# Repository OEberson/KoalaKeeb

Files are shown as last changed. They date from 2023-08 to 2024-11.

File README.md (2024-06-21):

# KoalaKeeb

In this repo, I am sharing with you my ideal split keyboard, The KoalaKeeb. It is heavily inspired by the [Ferris Sweep](https://github.com/davidphilipbarr/Sweep) and borrows its physical layout. What it adds is ten SK6812 MINI-E LEDs next to the MCU that will be used to display the current battery status or bluetooth profile and a cute koala logo. I will implement the LED functionality in [my ZMK fork](https://github.com/OEberson/zmkoala) soon.

Note that the current PCB version has some imperfections that I will improve on in a second revision.

[Link to my layout](https://github.com/OEberson/zmk-config)

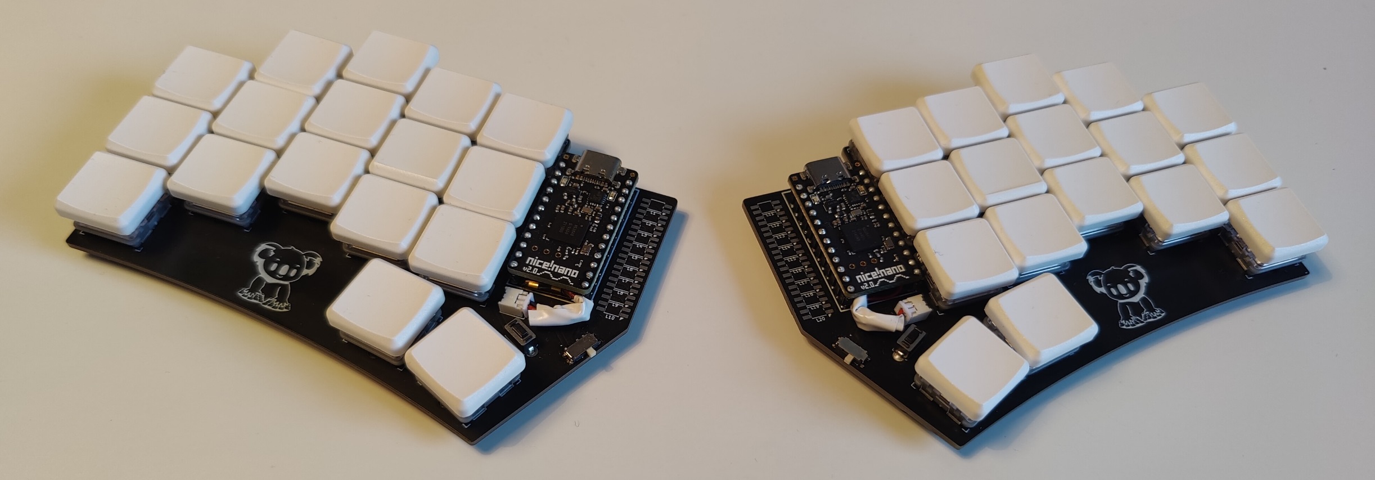
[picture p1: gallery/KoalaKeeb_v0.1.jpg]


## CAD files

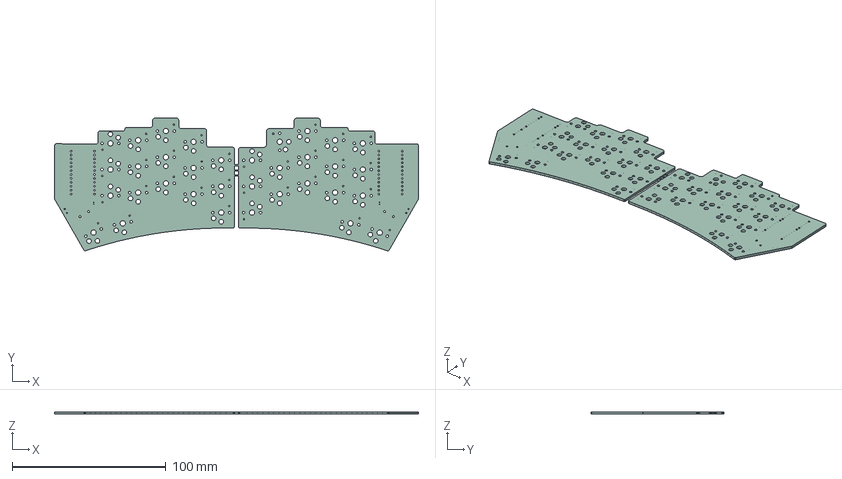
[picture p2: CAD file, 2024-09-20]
KiCad/KoalaKeeb/KoalaKeeb/KoalaKeeb.step
236.6 x 86.3 x 1.60 mm

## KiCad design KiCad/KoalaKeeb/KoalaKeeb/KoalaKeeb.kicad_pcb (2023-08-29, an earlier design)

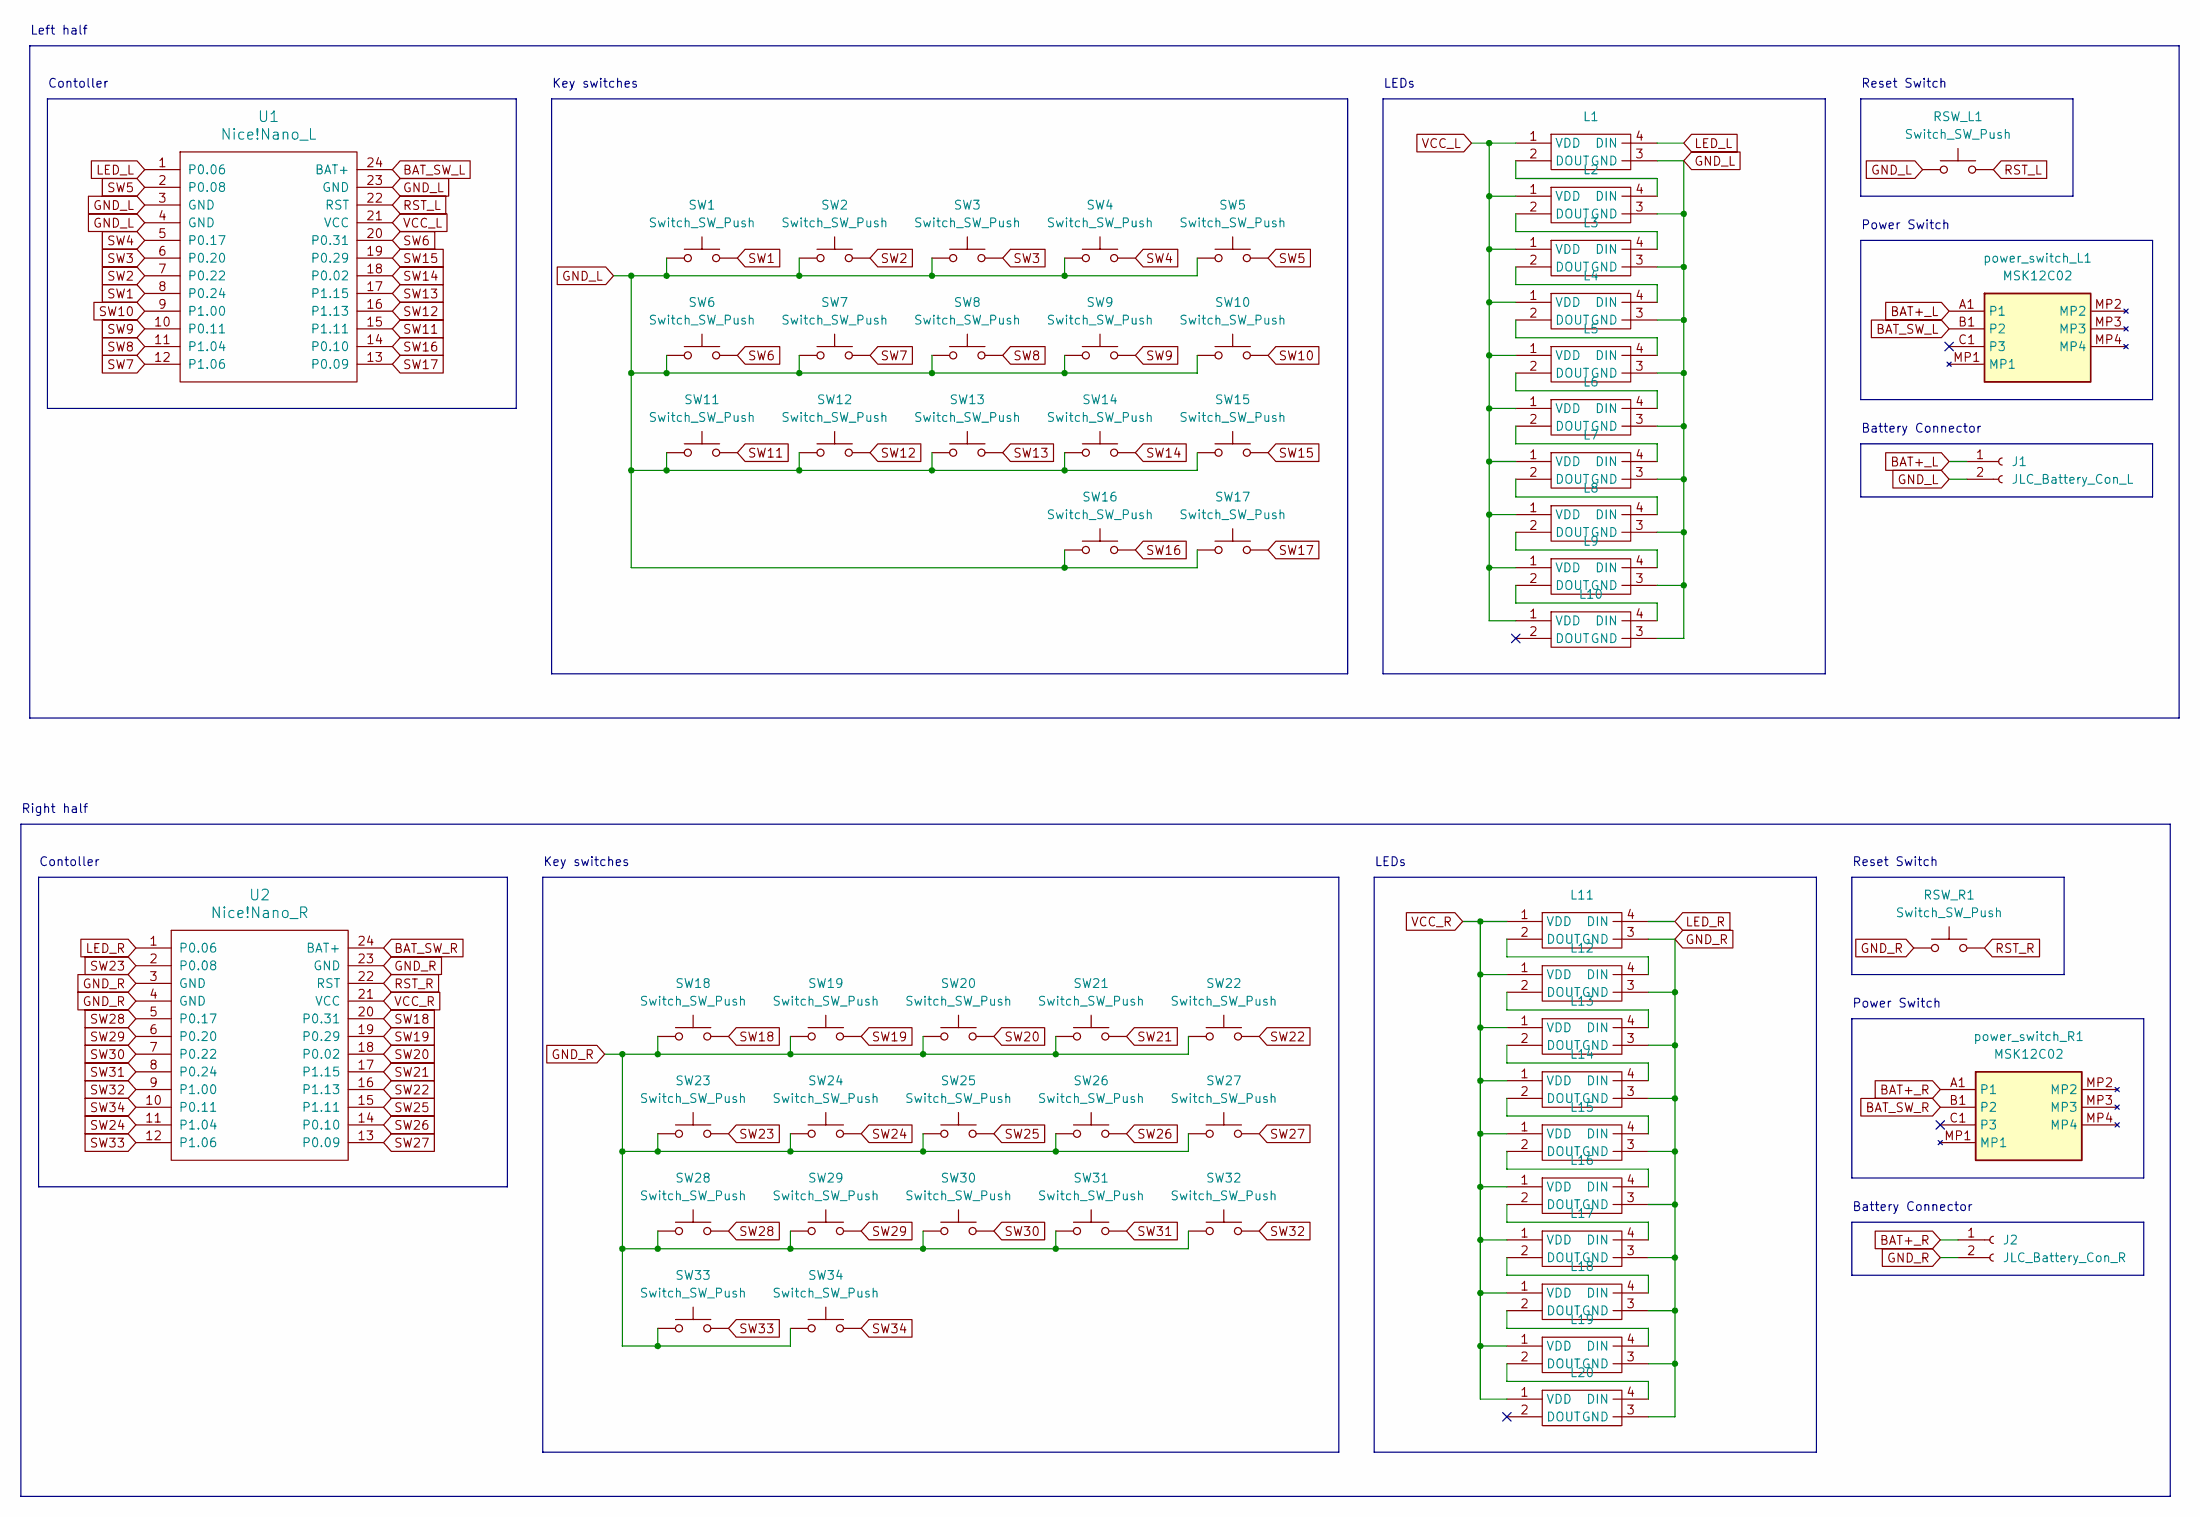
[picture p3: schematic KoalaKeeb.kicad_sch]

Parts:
J1: JLC_Battery_Con_L; JLC 2Pin
J2: JLC_Battery_Con_R; JLC 2Pin
L1, L2, L3, L4, L5, L6, L7, L8, L9, L10, L11, L12, L13, L14, L15, L16, L17, L18, L19, L20: SK6812-MINI-E
RSW_L1: Switch_SW_Push; TS-1136-4.3
RSW_R1: Switch_SW_Push; TS-1136-4.3
SW1, SW2, SW3, SW4, SW5, SW6, SW7, SW8, SW9, SW10, SW11, SW12, SW13, SW14, SW15, SW16, SW17, SW18, SW19, SW20, SW21, SW22, SW23, SW24, SW25, SW26, SW27, SW28, SW29, SW30, SW31, SW32, SW33, SW34: Switch_SW_Push; Kailh_socket_PG1350
U1: Nice!Nano_L; nice!nano
U2: Nice!Nano_R; nice!nano
power_switch_L1: MSK12C02; Manufacturer_Part_Number MSK12C02
power_switch_R1: MSK12C02; Manufacturer_Part_Number MSK12C02

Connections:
BAT+_L: J1.1, power_switch_L1.A1 (P1)
BAT+_R: J2.1, power_switch_R1.A1 (P1)
BAT_SW_L: U1.24 (BAT+), power_switch_L1.B1 (P2)
BAT_SW_R: U2.24 (BAT+), power_switch_R1.B1 (P2)
GND_L: J1.2, L1.3 (GND), L2.3 (GND), L3.3 (GND), L4.3 (GND), L5.3 (GND), L6.3 (GND), L7.3 (GND), L8.3 (GND), L9.3 (GND), L10.3 (GND), RSW_L1.1, SW1.1, SW2.1, SW3.1, SW4.1, SW5.1, SW6.1, SW7.1, SW8.1, SW9.1, SW10.1, SW11.1, SW12.1, SW13.1, SW14.1, SW15.1, SW16.1, SW17.1, U1.3 (GND), U1.4 (GND), U1.23 (GND)
GND_R: J2.2, L11.3 (GND), L12.3 (GND), L13.3 (GND), L14.3 (GND), L15.3 (GND), L16.3 (GND), L17.3 (GND), L18.3 (GND), L19.3 (GND), L20.3 (GND), RSW_R1.1, SW18.1, SW19.1, SW20.1, SW21.1, SW22.1, SW23.1, SW24.1, SW25.1, SW26.1, SW27.1, SW28.1, SW29.1, SW30.1, SW31.1, SW32.1, SW33.1, SW34.1, U2.3 (GND), U2.4 (GND), U2.23 (GND)
LED_L: L1.4 (DIN), U1.1 (P0.06)
LED_R: L11.4 (DIN), U2.1 (P0.06)
unnamed: L1.2 (DOUT), L2.4 (DIN)
unnamed: L2.2 (DOUT), L3.4 (DIN)
unnamed: L3.2 (DOUT), L4.4 (DIN)
unnamed: L4.2 (DOUT), L5.4 (DIN)
unnamed: L5.2 (DOUT), L6.4 (DIN)
unnamed: L6.2 (DOUT), L7.4 (DIN)
unnamed: L7.2 (DOUT), L8.4 (DIN)
unnamed: L8.2 (DOUT), L9.4 (DIN)
unnamed: L9.2 (DOUT), L10.4 (DIN)
unnamed: L11.2 (DOUT), L12.4 (DIN)
unnamed: L12.2 (DOUT), L13.4 (DIN)
unnamed: L13.2 (DOUT), L14.4 (DIN)
unnamed: L14.2 (DOUT), L15.4 (DIN)
unnamed: L15.2 (DOUT), L16.4 (DIN)
unnamed: L16.2 (DOUT), L17.4 (DIN)
unnamed: L17.2 (DOUT), L18.4 (DIN)
unnamed: L18.2 (DOUT), L19.4 (DIN)
unnamed: L19.2 (DOUT), L20.4 (DIN)
RST_L: RSW_L1.2, U1.22 (RST)
RST_R: RSW_R1.2, U2.22 (RST)
SW1: SW1.2, U1.8 (P0.24)
SW2: SW2.2, U1.7 (P0.22)
SW3: SW3.2, U1.6 (P0.20)
SW4: SW4.2, U1.5 (P0.17)
SW5: SW5.2, U1.2 (P0.08)
SW6: SW6.2, U1.20 (P0.31)
SW7: SW7.2, U1.12 (P1.06)
SW8: SW8.2, U1.11 (P1.04)
SW9: SW9.2, U1.10 (P0.11)
SW10: SW10.2, U1.9 (P1.00)
SW11: SW11.2, U1.15 (P1.11)
SW12: SW12.2, U1.16 (P1.13)
SW13: SW13.2, U1.17 (P1.15)
SW14: SW14.2, U1.18 (P0.02)
SW15: SW15.2, U1.19 (P0.29)
SW16: SW16.2, U1.14 (P0.10)
SW17: SW17.2, U1.13 (P0.09)
SW18: SW18.2, U2.20 (P0.31)
SW19: SW19.2, U2.19 (P0.29)
SW20: SW20.2, U2.18 (P0.02)
SW21: SW21.2, U2.17 (P1.15)
SW22: SW22.2, U2.16 (P1.13)
SW23: SW23.2, U2.2 (P0.08)
SW24: SW24.2, U2.11 (P1.04)
SW25: SW25.2, U2.15 (P1.11)
SW26: SW26.2, U2.14 (P0.10)
SW27: SW27.2, U2.13 (P0.09)
SW28: SW28.2, U2.5 (P0.17)
SW29: SW29.2, U2.6 (P0.20)
SW30: SW30.2, U2.7 (P0.22)
SW31: SW31.2, U2.8 (P0.24)
SW32: SW32.2, U2.9 (P1.00)
SW33: SW33.2, U2.12 (P1.06)
SW34: SW34.2, U2.10 (P0.11)
VCC_L: L1.1 (VDD), L2.1 (VDD), L3.1 (VDD), L4.1 (VDD), L5.1 (VDD), L6.1 (VDD), L7.1 (VDD), L8.1 (VDD), L9.1 (VDD), L10.1 (VDD), U1.21 (VCC)
VCC_R: L11.1 (VDD), L12.1 (VDD), L13.1 (VDD), L14.1 (VDD), L15.1 (VDD), L16.1 (VDD), L17.1 (VDD), L18.1 (VDD), L19.1 (VDD), L20.1 (VDD), U2.21 (VCC)

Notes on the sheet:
Contoller
Key switches
Reset Switch
Power Switch
LEDs
Left half
Battery Connector
Right half

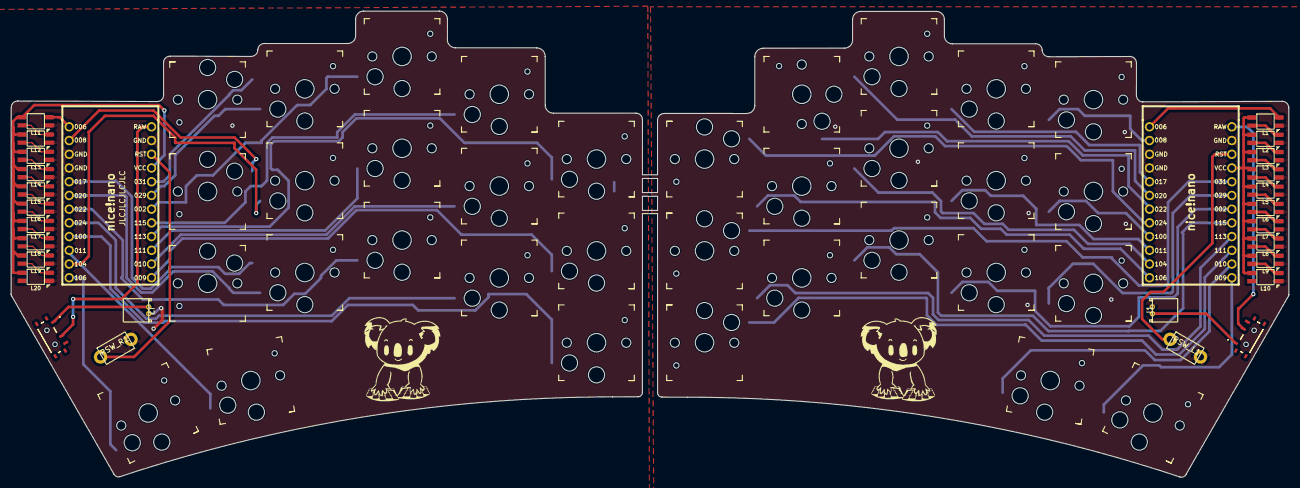
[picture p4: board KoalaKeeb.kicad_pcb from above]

Board: 2 copper layers, 236.6 x 86.3 mm, 62 parts (0 on the bottom side), 64 nets.

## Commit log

2023-08-19 remove transistor circuit
    [KoalaKeeb.kicad_sch]
2023-08-19 remove diodes
    [KoalaKeeb.kicad_sch]
2023-08-19 add right half
    [KoalaKeeb.kicad_sch]
2023-08-19 add and assing most footprints
    [KoalaKeeb.kicad_sch]
2023-08-20 add remaining footprints and create PCB
    [KoalaKeeb.kicad_pcb, KoalaKeeb.kicad_sch]
2023-08-20 add new footprints to git
2023-08-20 place all parts for left side
    [KoalaKeeb.kicad_pcb]
2023-08-20 place all components on PCB
    [KoalaKeeb.kicad_pcb]
2023-08-20 routing and outlines done
    [KoalaKeeb.kicad_pcb, KoalaKeeb.kicad_sch]
2023-08-20 connect PCB halves
    [KoalaKeeb.kicad_pcb]
2023-08-20 add text field for JLC serial number
    [KoalaKeeb.kicad_pcb]
2023-08-23 update routing for right half LEDs
    [KoalaKeeb.kicad_pcb, KoalaKeeb.kicad_sch]
2023-08-29 add logo and create gerber files
    [KoalaKeeb-B_Cu.gbl, KoalaKeeb-B_Mask.gbs, KoalaKeeb-B_Paste.gbp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]
2024-09-20 add step file
    [KoalaKeeb.step]
2024-09-20 fix LED footprint
2024-09-20 add v0.2 as extra files
    [KoalaKeeb_v0.2.kicad_pcb]
2024-09-20 add v0.2
    [KoalaKeeb_v0.2.kicad_pcb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]
2024-10-04 split v0.2 into left and right
    [KoalaKeeb-B_Cu.gbl, KoalaKeeb-B_Mask.gbs, KoalaKeeb-B_Paste.gbp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]
2024-11-22 add v1
    [KoalaKeeb_v1-B_Cu.gbl, KoalaKeeb_v1-B_Mask.gbs, KoalaKeeb_v1-B_Paste.gbp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]
